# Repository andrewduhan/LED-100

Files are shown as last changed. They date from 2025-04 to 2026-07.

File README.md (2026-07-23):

**A drop-in replacement for early Stern & Bally lamp driver boards to make your lamps s~m~o~o~t~h again**

> ⚠️ **This is Rev 5 - work in progress.** 
> This board is still being developed and tested. Everything may change before release! 

---

## What is this?

Early Stern and Bally solid-state pinball machines (mid-1970s to the mid-80s) use incandescent bulbs. It's awesome to swap those bulbs for LEDs (less power draw, less heat, less maintenance)...  but: LEDs switch on and off instantly, and this makes old tables flash & strobe in a nasty way.

The LED-100 fixes that. You install it in place of the original board. It reads the lamp codes exactly like the original did, and drives your LEDs with a gentle fade - keep that warm glowing feel without the actual heat - your LEDs will behave more like real bulbs.

**Will this work for your machine?** See [Compatibility](#compatability) below.

---

## Will it work on my machine?

Two things have to be true:
1. Your machine was designed to use one of the supported lamp driver boards.
2. Every lamp this board controls has already been swapped with an LED. I don't know what it'll do if you try and drive incandescents.

**What this board does _not_ do:** it only drives the lamps that ran through the original lamp driver board. It has nothing to do with your machine's GI or any high-current feature/flasher lamps that are driven from the solenoid driver board. Those are separate systems and are not controlled by this board.

---

## How to use it

Once installed, there's nothing to operate - power the machine on and tit does what it does.

There are a couple of controls on the board.

- **s~m~o~o~t~h knob** - Turn this to adjust the fade-speed. All the way up will probably be way too gooey, all the way off will essentially diable the board, and your LEDs will snap on and off like before. (Fade-out is always a little slower than fade-in, 'cause that's now incandescent lamps work.)
- **A button and another knob** - These are placeholders right now. The button currently cycles through some demo/test modes, which ignore input from the MPU. The knob tweaks overall brightness.

---

## Installing it

The board is fully pin-compatible with the original — same connectors, same `J1`–`J4` labels, so swapping it in is straightforward:

1. **Turn off and unplug the machine.** C'mon.
2. Unplug the cables from the original lamp driver board. You might want to label the cables according to the markings on the board - `J1`, `J2`, `J3`, and `J4`
3. Unbolt and remove the original board from the backbox†.
4. Bolt the LED-100 into the backbox*.
5. Plug the same four cables onto the matching headers on the LED-100, `J1`-`J4`.  These are keyed, so check that they are oriented correctly.

†**Mounting (Rev 5)**: This board revision is much smaller than the original, so the mounting holes don't line up with the factory bolt points. You can get one bolt in, but not the rest. 
The final version will have a better mounting solution, but for now: secure it with the single bolt that does line up, and make sure no pins, traces, or solder joints on the back of the board are touching metal.

---

## What's in this git repository

Everything you need to understand, build, modify, or reproduce the board:

- **[`LED-100-hardware/`]()** — the circuit board: KiCad schematic and layout, plus the gerbers used to produce this rev.
- **[`LED-100-firmware/`]()** — the code that runs on the board's Teensy 4.0, with its own [README]() covering how it works, the pin map, and how to build and flash it.

---

## How It Works, the short technical version

The board reads the machine's original lamp-matrix signals, works out which lamps should be lit, and drives LEDs through three PWM LED drivers (TLC5947). A [Teensy 4.0] is the brain that runs the whole thing. The fade curves are calculated is done in software, so the glow-up and fade-out curves are adjustable. Full detail is in the [firmware README]().

Here's how the PCB looks in KiCad:

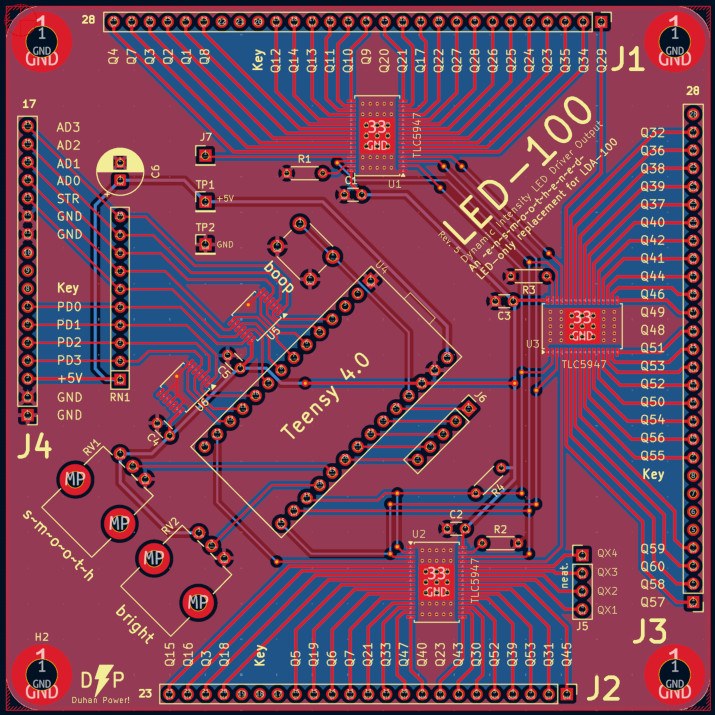
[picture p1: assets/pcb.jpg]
 

...and here's the schematic:

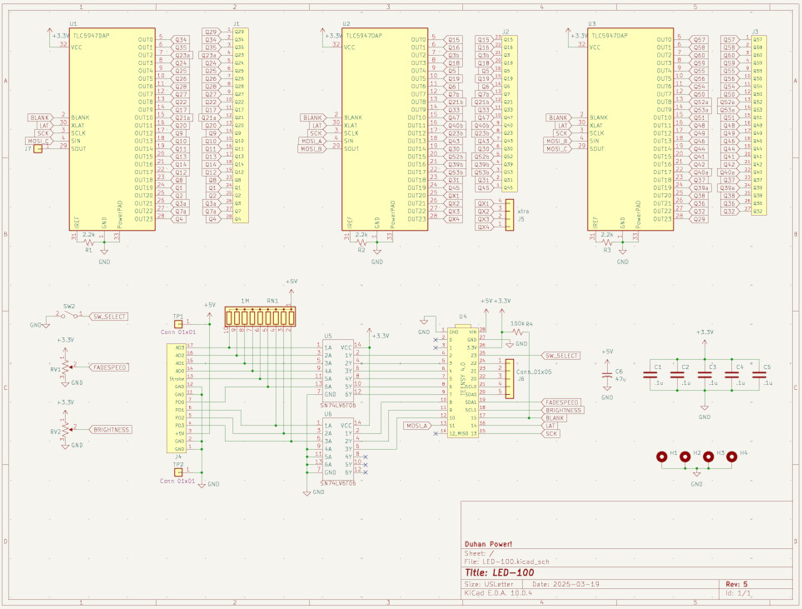
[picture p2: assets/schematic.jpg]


---

## Compatibility

> **NOTE:** The LED-100 doesn't yet work in any machine; this list is the _intended_ target, not a tested one. The **Stern LDA-100** is the active development board. Once it's working there, I'll try it in any compatible machine I can :)

The LED-100 is meant to replace several factory lamp driver boards, which are all electrically equivalent. 

| Board | Manufacturer |
| --- | --- |
| Stern LDA-100 | Stern |
| Stern LDB-100 | Stern |
| Bally AS-2518-14 | Bally |
| Bally AS-2518-23 | Bally |
| Bally A084-91612-A000 | Bally |

Not sure which board your machine has? Check the part number silkscreened on the original board, or your machine's service manual.

---

## License

Firmware and hardware are licensed under the terms in the LICENSE file, in their respective directories.

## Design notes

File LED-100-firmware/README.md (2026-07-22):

# LED-100 firmware

A drop-in replacement for the lamp-driver board in an early solid-state pinball
machine.

The machine's MPU still speaks its original lamp-matrix protocol. This board
listens to that protocol and drives LEDs — which have replaced the machine's
incandescent lamps — through three chained TLC5947 constant-current drivers. The
whole point is the **fade**: real incandescent bulbs glow up and die away, and
LEDs switched hard on and off look wrong in a way you notice immediately. This
board puts the glow back.

It runs on a **Teensy 4.0** under the Arduino IDE with Teensyduino.

---

## How it works, in one picture

```
   MPU lamp matrix ──▶ decoder ──┐
                                 ├──▶ one 64-bit lamp bitmap ──▶ fade engine ──▶ TLC5947 ──▶ LEDs
   bench demo modes ─────────────┘
```

The MPU and the built-in demo modes are interchangeable sources: both hand off a
completed "which lamps are lit" bitmap the exact same way, so everything after
that point behaves identically whether you're driving from a real machine or
from a bench pattern.

---

## Hardware

- **Teensy 4.0** — the microcontroller.
- **Interface board** — sits between the MPU and the Teensy. The MPU's signals
  are 5 V and the Teensy's pins are 3.3 V-only, so the interface board handles
  the level shifting. **Heads up:** the current prototype interface board may
  have damaged some Teensy input pins by feeding them 5 V directly; a redesign is
  on the way. Until it lands, treat the live-decode path as unverified (the fade
  side is fully working — see [Status](#status)).
- **Three TLC5947 drivers**, chained — 24 channels each, 72 total, of which 60
  correspond to the original machine's lamps.
- **LEDs** in place of the original incandescent lamps.
- A **momentary push-button** (mode select) and a **potentiometer** (fade speed)
  on the front panel. A second pot is on the board but isn't read by the firmware
  yet.

### Pin map

The authoritative copy of this lives in the `#define`s at the top of
[`LED-100-firmware.ino`](LED-100-firmware.ino) — if these ever disagree,
believe the code.

| Signal | Teensy pin | Notes |
| --- | --- | --- |
| AD0–AD3 | 5, 4, 3, 2 | Address lines from the MPU |
| PD0–PD3 | 7, 8, 9, 10 | Group-enable lines (the original board's W/X/Y/Z) |
| STROBE | 6 | Address latch |
| TLC clock / data / latch / blank | 13 / 12 / 14 / 15 | To the first TLC5947 |
| Mode button | 23 | Momentary to ground |
| Fade-speed pot | A3 | Wiper to the pin, ends to 3.3 V and ground |
| Second pot | A2 | Placeholder — on the board, nothing reads it yet |

Signal names follow the original board's schematic, so the code, a scope probe,
and the machine's service manual all use the same labels.

### Wiring the TLC5947 BLANK pin

This is the one wiring detail most likely to trip you up, so it's called out
here as well as in the driver header. Best option first:

1. **BLANK → a Teensy pin, with a pull-up resistor to 3.3 V** (what this board
   does). Clean startup, no dimming. Recommended.
2. **BLANK tied to ground**, not wired to the Teensy. Works, but you'll get a
   brief flash of garbage at power-on and slightly dimmer LEDs *while they're
   fading*. Neither is fixable in software.

The full explanation is in the header comment of
[`TLC5947.h`](TLC5947.h).

---

## Using it

**Normal operation** needs no interaction: power it up and it decodes the MPU
and drives the lamps.

**The push-button** cycles between live input and three LED test patterns —
random, flash-all, and sequential. The patterns ignore the MPU entirely, which
makes them handy for checking the LEDs and the fade feel on the bench with
nothing else connected. They're a development aid and may not survive to the
final build (`ENABLE_DEMO_MODES` in the sketch drops them, and the button with
them); what the button ends up doing on a finished board is still open.

**The potentiometer** sets the fade speed. Fade-out is always slower than
fade-in, mimicking how a filament cools more slowly than it heats. It's meant to
be set once with the backbox open and then left alone.

---

## Configuring it

The knobs a builder actually touches, all near the top of
[`LED-100-firmware.ino`](LED-100-firmware.ino):

- **`FADE_IN_CURVE` / `FADE_OUT_CURVE`** — the shape of the glow-up and
  die-away. Pick from the curves the fade engine offers
  ([`FadeEngine.h`](FadeEngine.h)).
- **`FADE_IN_MIN_MS` / `FADE_IN_MAX_MS` / `FADE_OUT_RATIO`** — the range the pot
  sweeps, and how much slower fade-out is than fade-in.
- **`NUM_TLC5947`** — number of chained driver chips, if your board differs.
- **Software vs. hardware SPI** — the driver supports both. This board currently
  uses bit-banged software SPI (the constructor call just below the pin
  `#define`s); the driver header explains the switch.

The **lamp map** — which of the 72 driver channels each incoming lamp lights — is
the `channelToLampBit` table in the sketch. It's specific to the machine and its
wiring, and is the thing to edit if a lamp lights the wrong LED.

---

## Building & flashing

1. Install the **Arduino IDE** and **[Teensyduino](https://www.pjrc.com/teensy/td_download.html)**.
2. Open [`LED-100-firmware.ino`](LED-100-firmware.ino).
3. Select **Tools → Board → Teensy 4.0**.
4. Upload.

No libraries to install: the `TLC5947` driver and the `FadeEngine` both live in
the sketch folder alongside the `.ino`.

---

## Status

- **Fade engine — working.** Demonstrated by the demo modes; this is the mature
  part of the project.
- **Live MPU decode — unverified.** The logic is written and reviewed, but can't
  be trusted on hardware until the redesigned interface board arrives (see
  [Hardware](#hardware)).
- **Lamp map — not yet reconciled.** `channelToLampBit` hasn't been checked
  against the real machine and is known to be at least partly wrong: a few driver
  channels are currently mapped to lamp positions that can never light, and a few
  real lamps aren't mapped to any channel. Flagged in the code; a proper pass is
  pending.

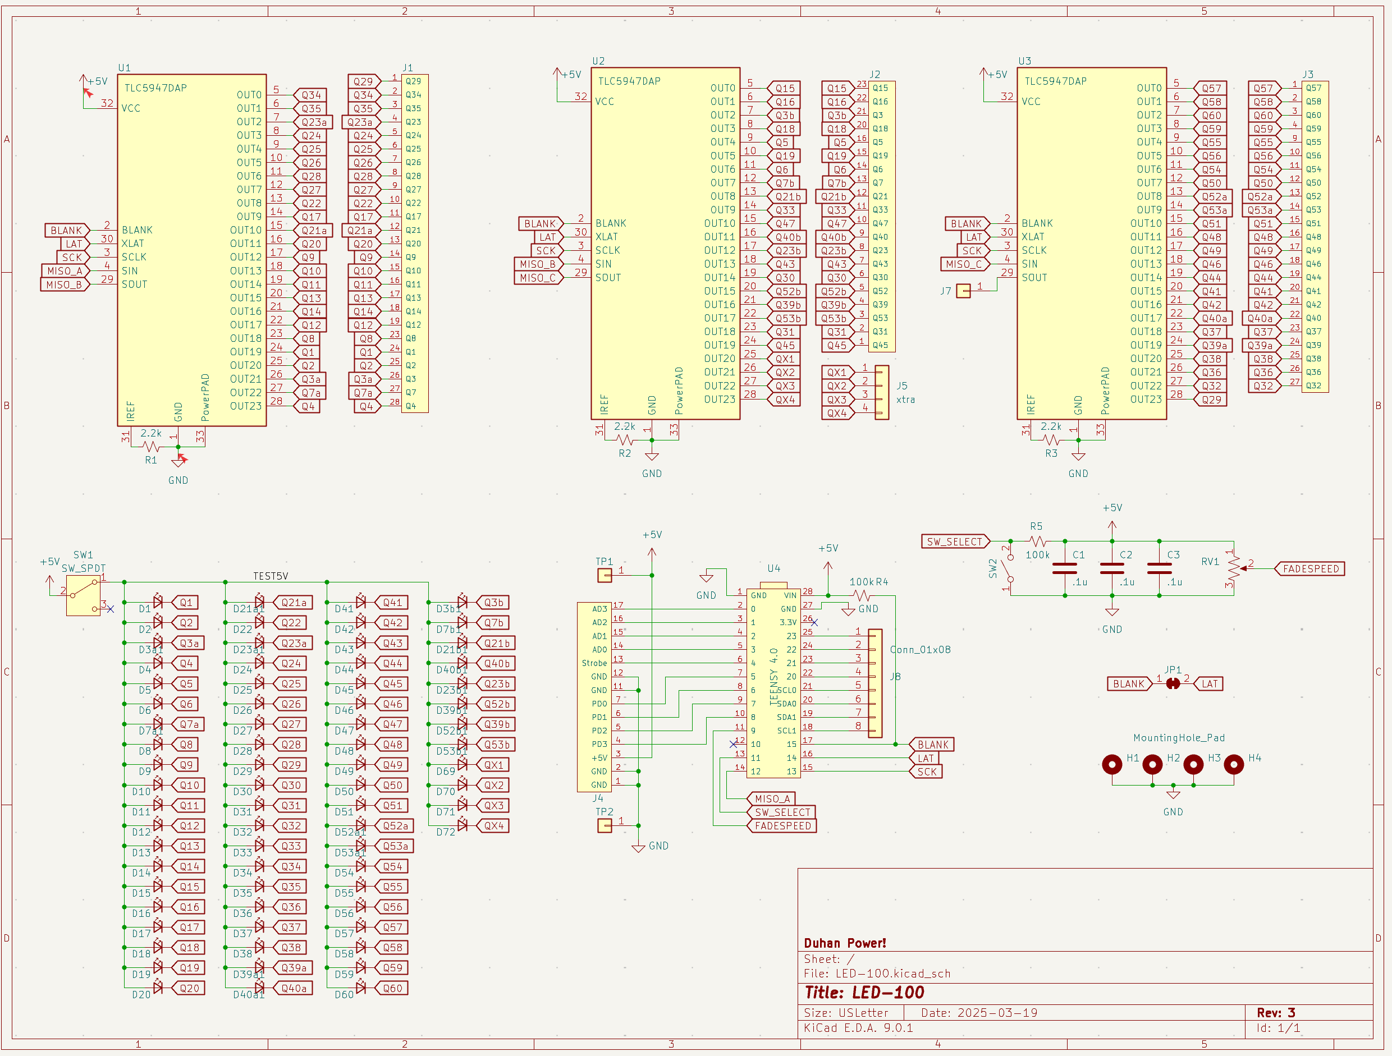
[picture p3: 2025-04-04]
assets/schematic.png

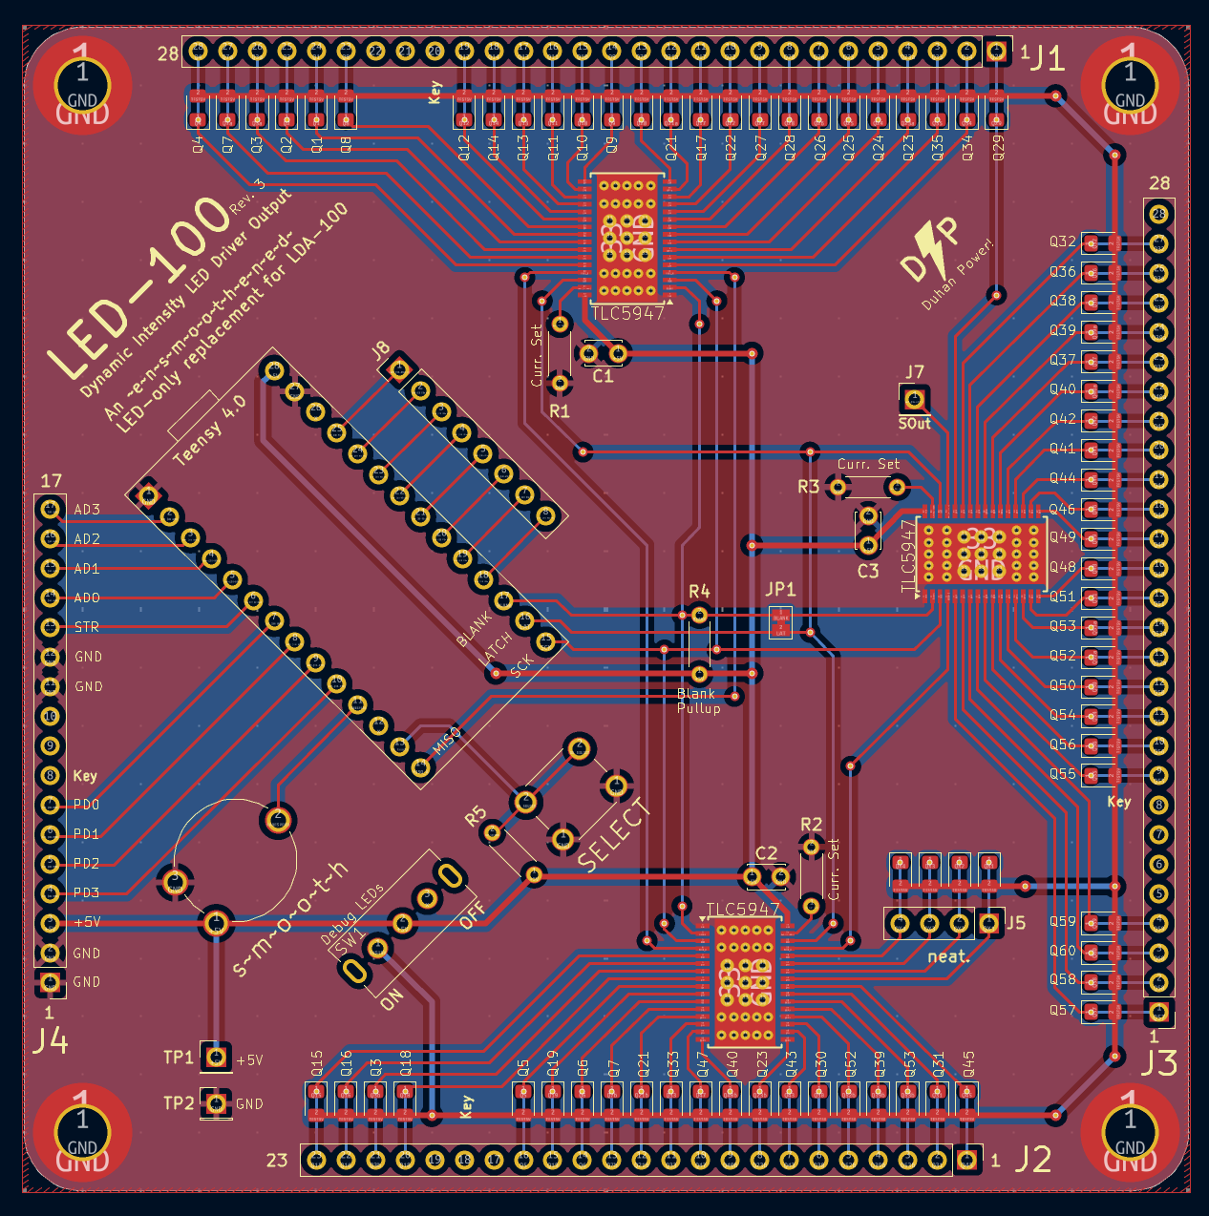
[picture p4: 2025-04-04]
assets/pcb.png

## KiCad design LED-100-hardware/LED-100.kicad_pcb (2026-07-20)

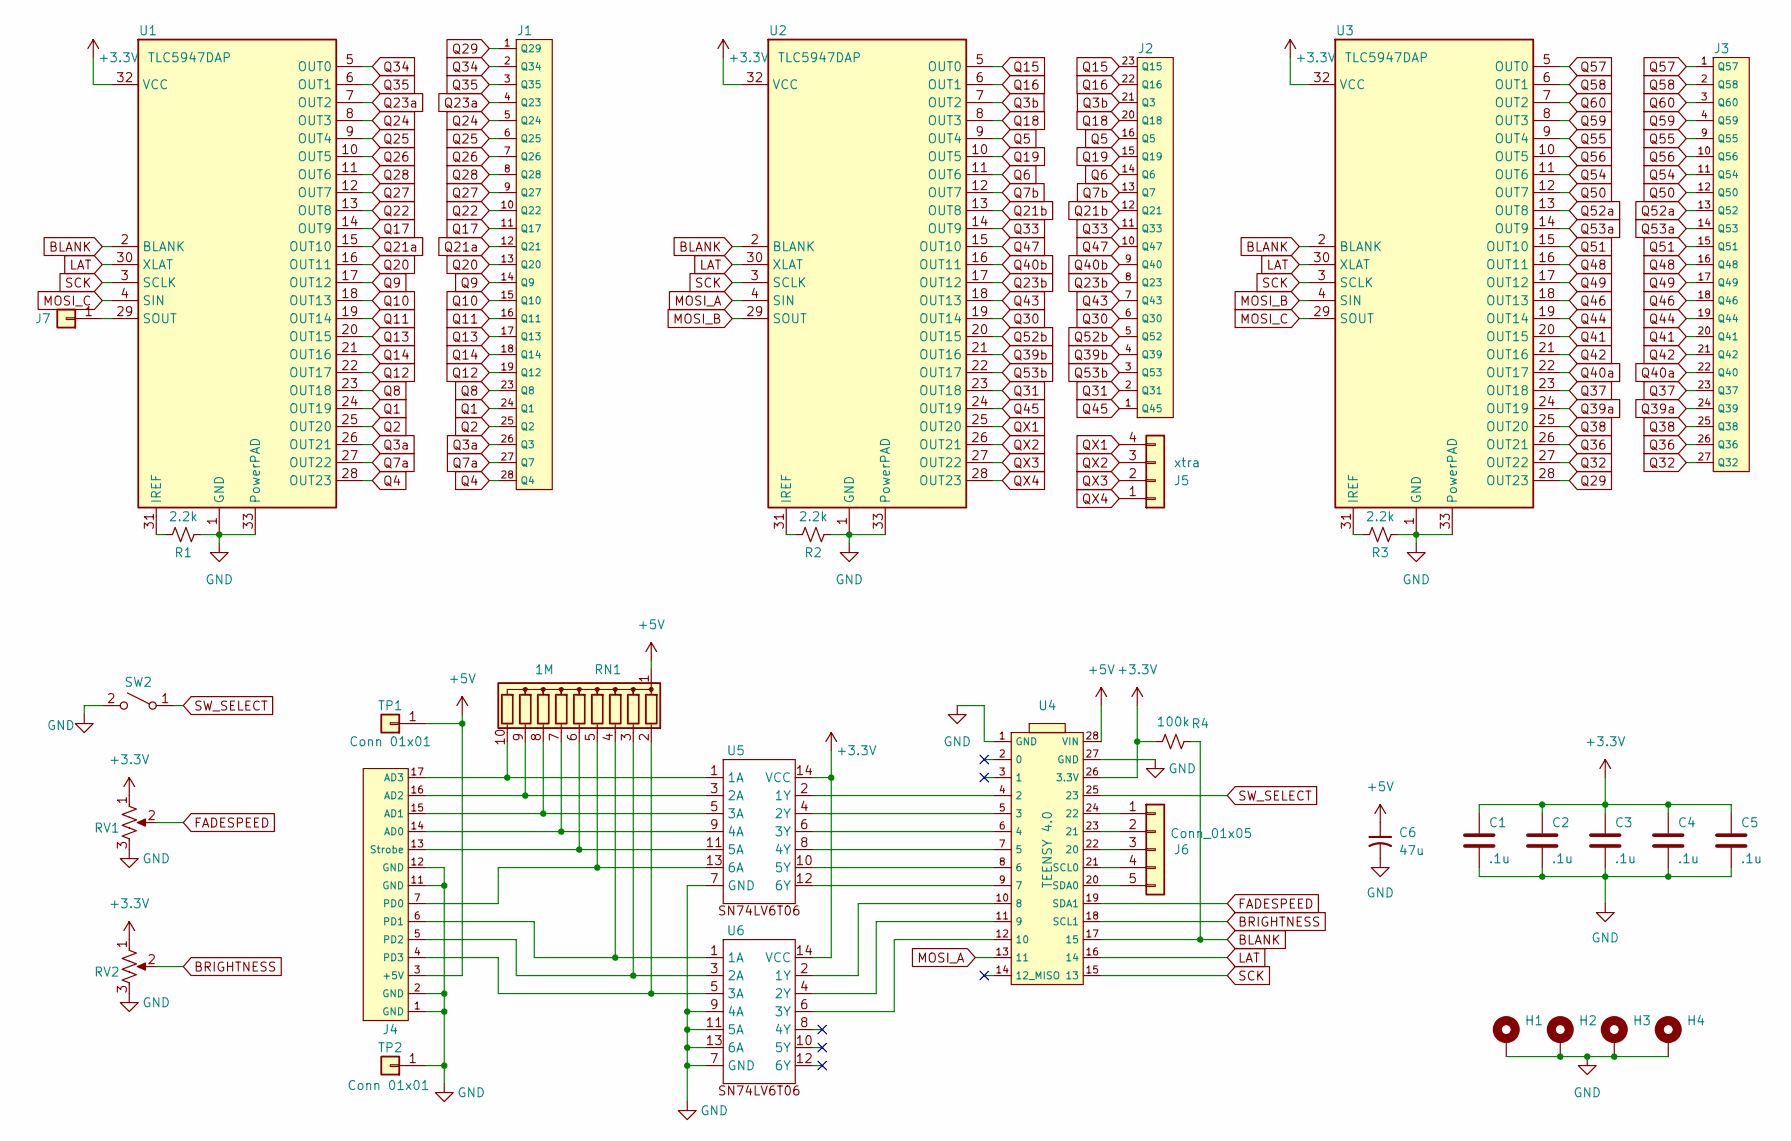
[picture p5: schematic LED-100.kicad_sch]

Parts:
C1, C2, C3, C4, C5: .1u; C_Disc_D3.0mm_W1.6mm_P2.50mm
C6: 47u; CP_Radial_D6.3mm_P2.50mm
H1, H2, H3, H4: MountingHole_Pad; MountingHole_4.3mm_M4_Pad_TopBottom
J1: PinHeader_1x28_P2.54mm_Vertical
J2: LDA100_2_J2; PinHeader_1x23_P2.54mm_Vertical
J3: LDA100_2_J3; PinHeader_1x28_P2.54mm_Vertical
J4: LDA100_2_J4; PinHeader_1x17_P2.54mm_Vertical
J5: xtra; PinHeader_1x04_P2.54mm_Vertical
J6: Conn_01x05; PinHeader_1x05_P2.54mm_Vertical
J7: Conn_01x01; PinHeader_1x01_P2.54mm_Vertical
R1, R2, R3: 2.2k; R_Axial_DIN0204_L3.6mm_D1.6mm_P5.08mm_Horizontal
R4: 100k; R_Axial_DIN0204_L3.6mm_D1.6mm_P5.08mm_Horizontal
RN1: 1M; R_Array_SIP10
RV1, RV2: 100k; Potentiometer_Bourns_PTV09A-1_Single_Vertical
SW2: SW_SPST; SW_PUSH_6mm_H5mm
TP1, TP2: Conn_01x01; PinHeader_1x01_P2.54mm_Vertical
U1, U2, U3: TLC5947DAP; Package_SO_HTSSOP-32-1EP_6.1x11mm_P0.65mm_EP5.2x11mm_Mask4.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
U4: TEENSY 4.0; Teensy 4.0
U5, U6: TSSOP-14_4.4x5mm_P0.65mm

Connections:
+3.3V: C1.1, C2.1, C3.1, C4.1, C5.1, R4.1, RV1.1, RV2.1, U1.32 (VCC), U2.32 (VCC), U3.32 (VCC), U4.26 (3.3V), U5.14 (VCC), U6.14 (VCC)
+5V: C6.1, J4.3 (+5V), RN1.1 (common), TP1.1 (Pin_1_1), U4.28 (VIN)
BLANK: R4.2, U1.2 (BLANK), U2.2 (BLANK), U3.2 (BLANK), U4.17 (15)
BRIGHTNESS: RV2.2, U4.18 (SCL1)
FADESPEED: RV1.2, U4.19 (SDA1)
GND: C1.2, C2.2, C3.2, C4.2, C5.2, C6.2, H1.1 (1_1), H2.1 (1_1), H3.1 (1_1), H4.1 (1_1), J4.1 (GND), J4.2 (GND), J4.11 (GND), J4.12 (GND), R1.2, R2.2, R3.2, RV1.3, RV2.3, SW2.2 (B), TP2.1 (Pin_1_1), U1.1 (GND), U1.33 (PowerPAD), U2.1 (GND), U2.33 (PowerPAD), U3.1 (GND), U3.33 (PowerPAD), U4.1 (GND), U4.27 (GND), U5.7 (GND), U6.7 (GND), U6.9 (4A), U6.11 (5A), U6.13 (6A)
LAT: U1.30 (XLAT), U2.30 (XLAT), U3.30 (XLAT), U4.16 (14)
MOSI_A: U2.4 (SIN), U4.13 (11)
MOSI_B: U2.29 (SOUT), U3.4 (SIN)
MOSI_C: U1.4 (SIN), U3.29 (SOUT)
unnamed: J4.14 (AD0), RN1.7 (R6), U5.9 (4A)
unnamed: J4.15 (AD1), RN1.8 (R7), U5.5 (3A)
unnamed: J4.16 (AD2), RN1.9 (R8), U5.3 (2A)
unnamed: J4.17 (AD3), RN1.10 (R9), U5.1 (1A)
unnamed: J4.7 (PD0), RN1.5 (R4), U5.13 (6A)
unnamed: J4.6 (PD1), RN1.4 (R3), U6.1 (1A)
unnamed: J4.5 (PD2), RN1.3 (R2), U6.3 (2A)
unnamed: J4.4 (PD3), RN1.2 (R1), U6.5 (3A)
unnamed: J4.13 (Strobe), RN1.6 (R5), U5.11 (5A)
unnamed: J6.1, U4.24 (22)
unnamed: J6.2, U4.23 (21)
unnamed: J6.3, U4.22 (20)
unnamed: J6.4, U4.21 (SCL0)
unnamed: J6.5, U4.20 (SDA0)
unnamed: J7.1 (Pin_1_1), U1.29 (SOUT)
unnamed: R1.1, U1.31 (IREF)
unnamed: R2.1, U2.31 (IREF)
unnamed: R3.1, U3.31 (IREF)
unnamed: U4.4 (2), U5.2 (1Y)
unnamed: U4.5 (3), U5.4 (2Y)
unnamed: U4.6 (4), U5.6 (3Y)
unnamed: U4.7 (5), U5.8 (4Y)
unnamed: U4.8 (6), U5.10 (5Y)
unnamed: U4.9 (7), U5.12 (6Y)
unnamed: U4.10 (8), U6.2 (1Y)
unnamed: U4.11 (9), U6.4 (2Y)
unnamed: U4.12 (10), U6.6 (3Y)
Q1: J1.24 (Q1), U1.24 (OUT19)
Q2: J1.25 (Q2), U1.25 (OUT20)
Q3a: J1.26 (Q3), U1.26 (OUT21)
Q3b: J2.21 (Q3), U2.7 (OUT2)
Q4: J1.28 (Q4), U1.28 (OUT23)
Q5: J2.16 (Q5), U2.9 (OUT4)
Q6: J2.14 (Q6), U2.11 (OUT6)
Q7a: J1.27 (Q7), U1.27 (OUT22)
Q7b: J2.13 (Q7), U2.12 (OUT7)
Q8: J1.23 (Q8), U1.23 (OUT18)
Q9: J1.14 (Q9), U1.17 (OUT12)
Q10: J1.15 (Q10), U1.18 (OUT13)
Q11: J1.16 (Q11), U1.19 (OUT14)
Q12: J1.19 (Q12), U1.22 (OUT17)
Q13: J1.17 (Q13), U1.20 (OUT15)
Q14: J1.18 (Q14), U1.21 (OUT16)
Q15: J2.23 (Q15), U2.5 (OUT0)
Q16: J2.22 (Q16), U2.6 (OUT1)
Q17: J1.11 (Q17), U1.14 (OUT9)
Q18: J2.20 (Q18), U2.8 (OUT3)
Q19: J2.15 (Q19), U2.10 (OUT5)
Q20: J1.13 (Q20), U1.16 (OUT11)
Q21a: J1.12 (Q21), U1.15 (OUT10)
Q21b: J2.12 (Q21), U2.13 (OUT8)
Q22: J1.10 (Q22), U1.13 (OUT8)
Q23a: J1.4 (Q23), U1.7 (OUT2)
Q23b: J2.8 (Q23), U2.17 (OUT12)
Q24: J1.5 (Q24), U1.8 (OUT3)
Q25: J1.6 (Q25), U1.9 (OUT4)
Q26: J1.7 (Q26), U1.10 (OUT5)
Q27: J1.9 (Q27), U1.12 (OUT7)
Q28: J1.8 (Q28), U1.11 (OUT6)
Q29: J1.1 (Q29), U3.28 (OUT23)
Q30: J2.6 (Q30), U2.19 (OUT14)
Q31: J2.2 (Q31), U2.23 (OUT18)
Q32: J3.27 (Q32), U3.27 (OUT22)
Q33: J2.11 (Q33), U2.14 (OUT9)
Q34: J1.2 (Q34), U1.5 (OUT0)
Q35: J1.3 (Q35), U1.6 (OUT1)
Q36: J3.26 (Q36), U3.26 (OUT21)
Q37: J3.23 (Q37), U3.23 (OUT18)
Q38: J3.25 (Q38), U3.25 (OUT20)
Q39a: J3.24 (Q39), U3.24 (OUT19)
Q39b: J2.4 (Q39), U2.21 (OUT16)
Q40a: J3.22 (Q40), U3.22 (OUT17)
Q40b: J2.9 (Q40), U2.16 (OUT11)
Q41: J3.20 (Q41), U3.20 (OUT15)
Q42: J3.21 (Q42), U3.21 (OUT16)
Q43: J2.7 (Q43), U2.18 (OUT13)
Q44: J3.19 (Q44), U3.19 (OUT14)
Q45: J2.1 (Q45), U2.24 (OUT19)
Q46: J3.18 (Q46), U3.18 (OUT13)
Q47: J2.10 (Q47), U2.15 (OUT10)
Q48: J3.16 (Q48), U3.16 (OUT11)
Q49: J3.17 (Q49), U3.17 (OUT12)
Q50: J3.12 (Q50), U3.12 (OUT7)
Q51: J3.15 (Q51), U3.15 (OUT10)
Q52a: J3.13 (Q52), U3.13 (OUT8)
Q52b: J2.5 (Q52), U2.20 (OUT15)
Q53a: J3.14 (Q53), U3.14 (OUT9)
Q53b: J2.3 (Q53), U2.22 (OUT17)
Q54: J3.11 (Q54), U3.11 (OUT6)
Q55: J3.9 (Q55), U3.9 (OUT4)
Q56: J3.10 (Q56), U3.10 (OUT5)
Q57: J3.1 (Q57), U3.5 (OUT0)
Q58: J3.2 (Q58), U3.6 (OUT1)
Q59: J3.4 (Q59), U3.8 (OUT3)
Q60: J3.3 (Q60), U3.7 (OUT2)
QX1: J5.4, U2.25 (OUT20)
QX2: J5.3, U2.26 (OUT21)
QX3: J5.2, U2.27 (OUT22)
QX4: J5.1, U2.28 (OUT23)
SCK: U1.3 (SCLK), U2.3 (SCLK), U3.3 (SCLK), U4.15 (13)
SW_SELECT: SW2.1 (A), U4.25 (23)

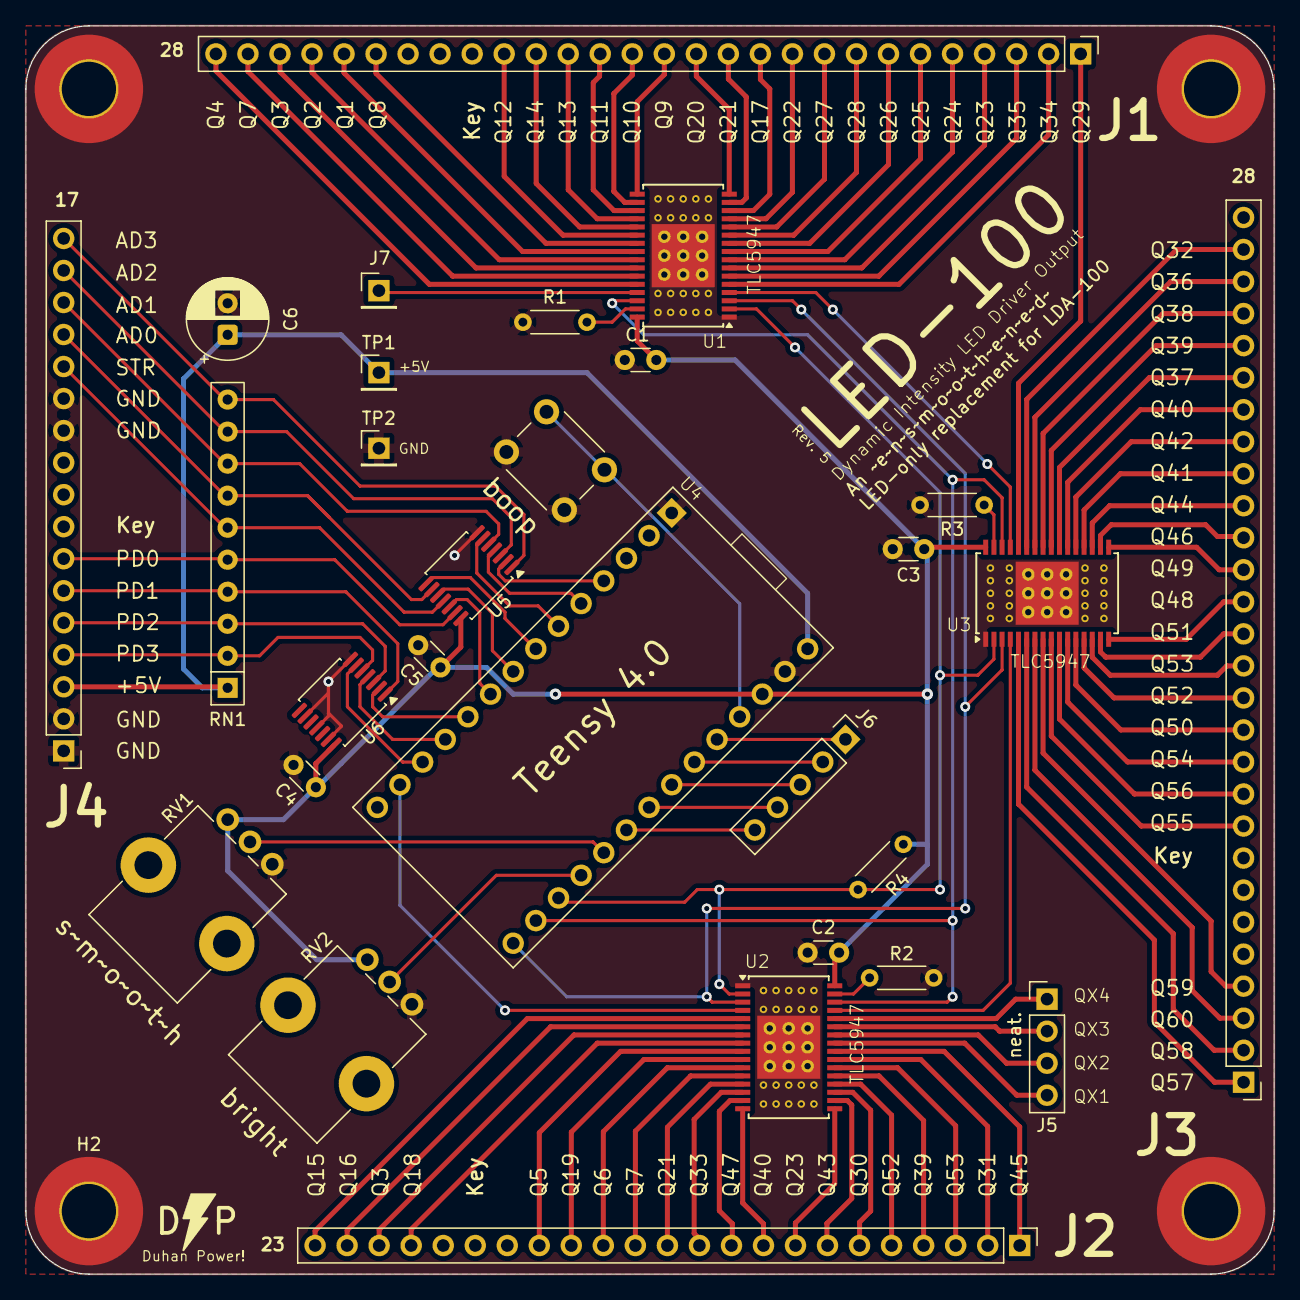
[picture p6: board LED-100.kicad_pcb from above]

Board: 2 copper layers, 99.0 x 99.0 mm, 33 parts (0 on the bottom side), 111 nets.

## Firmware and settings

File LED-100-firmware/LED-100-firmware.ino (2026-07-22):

/*
  Lamp-matrix decoder -> fade engine -> TLC5947 driver
  Teensy 4.0 / TeensyDuino

  Replaces the lamp-driver board in an early solid-state pinball machine.
  The MPU still speaks its original lamp-matrix protocol; this board decodes it, and drives LEDs (which have replaced the machine's
  incandescent lamps) through three chained TLC5947 constant-current drivers. The point of the exercise is the fade: incandescent 
  lamps glow up and die away, and LEDs switched hard on and off look wrong in a way you notice immediately.

  Signal names match the original board's schematic, so that this code, a scope probe and the service manual all agree:
    AD0..AD3  - the 4 address lines
    PD0..PD3  - the 4 group-enable lines (the original W/X/Y/Z)
    STROBE    - address latch

  PROTOCOL
  --------
  - All 9 input lines idle HIGH -> INPUT_PULLUP throughout.
  - AD0..AD3 carry an address 0-15, latched on STROBE's rising edge (STROBE is active-HIGH).
  - PD0..PD3 are active-LOW, driven by 4 parallel latching decoders (MC14514B) fed from the same address lines. Critically, they 
    assert *after* STROBE - each pulses low independently, sometime before the next STROBE. They are NOT sampled at the same 
    instant as the address. A falling edge on one of them means "the address STROBE most recently latched applies to my group", 
    so capture reacts to PD edges directly rather than reading all four at strobe time.
  - Addresses 0-14 are the 15 data addresses. 15 addresses x 4 groups = the 60 lamps of the original matrix. A lamp is identified 
    throughout this file by its bit index:  lampBit = pd * 16 + addr.
  - Address 15 is the end-of-frame sentinel and carries no data.
  - Frames arrive tied to AC zero-crossing (~120/sec), not a fixed clock. A whole 16-strobe frame completes well inside one 
    ~8.3ms half-cycle, so there is no time pressure on any ISR here.

  SHARING THE BUS WITH ANOTHER BOARD
  ----------------------------------
  Another board strobes this same bus, and its traffic has to be rejected. Two facts, both confirmed on the bench, make that possible:

  1. Interloper strobes only ever report address 15 (their decoder's "15" output is deliberately left unconnected). They never 
    present 0-14. So any address in 0-14 is ours and can be accepted on sight.

  2. Address 15 is therefore ambiguous - it is both our end-of-frame marker and every interloper strobe. Context resolves it: 
    a genuine end-of-frame 15 only ever arrives directly after address 14, the last data address. A 15 seen at any other moment 
    is an interloper, and is ignored.

  Interloper strobes also make their own PD lines pulse, which would otherwise look like real data for whatever address we last 
  latched. So a PD pulse is only trusted if no strobe of any kind has moved the bus since we latched: lastStrobeAddr must still 
  equal latchedAddr. If the interloper strobed in between, lastStrobeAddr changed while latchedAddr did not, and the mismatch 
  discards the pulse.

  Address 0 reliably marks a genuine frame start (confirmed it doesn't appear as noise), so it doubles as the resync point.

  ARCHITECTURE
  ------------
  Everything flows through one 64-bit lamp bitmap, published once per frame:

      decoder ISRs  --\
                       >-- publishFrame() -> takeFrame() -> FadeEngine -> TLC5947
      demo modes    --/

  The demo modes are a stand-in for the MPU: they publish frames exactly as the decoder does, so every stage downstream is 
  identical whether the lamps are being driven by a real machine or by a bench pattern. Deleting the demos for the final build 
  means deleting one section and one call.

  The five pin ISRs are the only interrupt code in the project. Fading runs on a timer gate in loop(), which is otherwise idle - 
  the fade needs to be regular, not instantaneous, and keeping it out of interrupt context is what lets it be an ordinary object 
  with no volatile state.
*/

#include "TLC5947.h"
#include "FadeEngine.h"

// Set to 0 for the final build: drops the bench demo patterns and the button that cycles them, leaving only live decode.
#define ENABLE_DEMO_MODES 1

// Set to 0 for the final build: drops the CPU load meter and its Serial output. See the LOAD METER section below.
#define ENABLE_LOAD_METER 1

// ==================================================================
// Configuration
// ==================================================================

// ---- TLC5947 LED drivers ----
#define NUM_TLC5947   3
#define NUM_CHANNELS  (NUM_TLC5947 * 24)   // 72
#define MAX_LEVEL     4095                 // TLC5947 is 12-bit

// Software (bit-banged) SPI. The prototype interface board has the data pin mis-assigned, so hardware SPI is not usable on it; 
// the driver supports both, and this becomes the hardware-SPI constructor once the redesigned board arrives. Bit-banging 72 
// channels costs ~150us per write, which at the fade tick rate below is a few percent of one core. It is not a problem.
#define TLC_CLOCK 13
#define TLC_DATA  12
#define TLC_LATCH 14
#define TLC_BLANK 15
TLC5947 tlc(NUM_TLC5947, TLC_CLOCK, TLC_DATA, TLC_LATCH, TLC_BLANK);

// ---- Inputs from the MPU ----
#define PIN_AD0    5
#define PIN_AD1    4
#define PIN_AD2    3
#define PIN_AD3    2
#define PIN_PD0    7
#define PIN_PD1    8
#define PIN_PD2    9
#define PIN_PD3    10
#define PIN_STROBE 6   // must be interrupt-capable (all Teensy 4 pins are)

// ---- Front-panel controls ----
#define PIN_DEMO_SWITCH 23   // momentary to GND -> pullup, active low
#define PIN_POT_FADE    A3   // one pot; sets fade-in, fade-out follows it
#define PIN_POT_BRIGHT  A2   // placeholder: the pot is on the board but nothing reads it yet. Current idea is scaling max output
                             // brightness below 100%, but it may become fade-out time instead, or be dropped to save BOM cost.

// ---- Fade behaviour ----
const uint32_t FADE_TICK_MS = 5;     // 200Hz; well above flicker perception

// The pot sets the fade-in time; fade-out is always this much slower, to mimic a filament cooling more slowly than it heats.
const uint16_t FADE_IN_MIN_MS  = 10;
const uint16_t FADE_IN_MAX_MS  = 200;
const float    FADE_OUT_RATIO  = 3.5f;   // so fade-out spans 35ms .. 700ms

const FadeCurve FADE_IN_CURVE  = FadeCurve::ExpoIn;
const FadeCurve FADE_OUT_CURVE = FadeCurve::LogOut;

FadeEngine fade(NUM_CHANNELS, MAX_LEVEL);

// ---- Control polling ----
const uint32_t POT_POLL_MS    = 250;   // set once with the backbox open, then never touched - slow is fine, and the deadband 
const uint16_t POT_DEADBAND   = 8;     // stops ADC noise wobbling the fade times between polls matches analogReadResolution(10)
const uint16_t POT_MAX        = 1023;  // matches analogReadResolution(10)
const uint32_t DEBOUNCE_MS    = 50;

// ==================================================================
// Lamp map
// ==================================================================
// Which lamp bit (pd * 16 + addr) drives which TLC5947 output channel. Several channels legitimately share a bit: some original 
// lamp drivers fed two SCRs, lighting the same signal on both the playfield and the backbox.
// DED marks a channel nothing drives; it is a dark-emitting LED.
//
// NOTE: this table has not yet been reconciled against the original board and is known to be at least partly wrong. 
// Channels 58, 68 and 71 map to bits 47, 31 and 15 - all of which are addr==15, the end-of-frame sentinel, so no PD pulse can 
// ever set them and those channels can never light. Lamp bits 60, 61 and 62 are meanwhile mapped to no channel at all. Left 
// as-is deliberately, pending a proper review against the machine.
const uint8_t DED = 0xFF;

const uint8_t channelToLampBit[NUM_CHANNELS] = {
  27, 12, 10, 28, 13, 29, 14, 11, 26, 42, 57, 40, 25, 58, 43, 55, 41, 56, 44, 59, DED, DED, DED, DED,
  45, 52, 50, 51, 49, 53, 48, 46, 55, 56, 47, 34, 33, 54, 32, 39, 38, 40, 35, 41, 31, 30, 36, 15,
  19, 18, 25, 23, 22, 21, 17, 16, 20, 24, 26, 37,  4,  5,  6,  2,  0,  1,  3,  8,  9, 10, 11,  7
};
static_assert(sizeof(channelToLampBit) == NUM_CHANNELS, "lamp map must have exactly one entry per TLC5947 channel");

// ==================================================================
// Frame handoff
// ==================================================================
// The one place a completed lamp bitmap is published, and the one place it is consumed. The decoder publishes from an ISR; 
// the demo modes publish from loop(). A uint64_t is not written atomically on a 32-bit core, so both ends guard the access - 
// and they do so by saving and restoring the interrupt mask rather than blindly re-enabling, which keeps them correct whether 
// the caller is inside an ISR or not.

// Which producer owns the handoff. Live is the real machine; the rest are bench patterns (see ENABLE_DEMO_MODES). 
// Exactly one publishes at a time.
enum class LampSource : uint8_t { Live, RandomFlicker, Blink, Chase };
volatile LampSource lampSource = LampSource::Live;

volatile uint64_t pendingFrame = 0;
volatile bool     frameFresh   = false;

// Save-and-restore of the interrupt mask, rather than noInterrupts() / interrupts(). The difference matters: 
// interrupts() unconditionally re-enables, so calling it from inside an ISR would drop the mask early.
// publishFrame() is called from an ISR (decode) and from loop() (demos), so it has to be correct in both.
static inline uint32_t irqSave() {
  uint32_t primask;
  __asm__ volatile("MRS %0, primask" : "=r"(primask) :: "memory");
  __asm__ volatile("CPSID i" ::: "memory");
  return primask;
}

static inline void irqRestore(uint32_t primask) {
  __asm__ volatile("MSR primask, %0" :: "r"(primask) : "memory");
}

void publishFrame(uint64_t lampBits) {
  const uint32_t mask = irqSave();
  pendingFrame = lampBits;
  frameFresh   = true;
  irqRestore(mask);
}

// Returns false if no new frame has arrived since the last call.
bool takeFrame(uint64_t &out) {
  bool got = false;
  const uint32_t mask = irqSave();
  if (frameFresh) {
    out        = pendingFrame;
    frameFresh = false;
    got        = true;
  }
  irqRestore(mask);
  return got;
}

// ==================================================================
// Decoder
// ==================================================================

const uint8_t ADDR_FRAME_START = 0;     // also the resync point
const uint8_t ADDR_LAST_DATA   = 14;    // 0..14 carry lamp data
const uint8_t ADDR_END_FRAME   = 15;    // sentinel; also every interloper strobe
const uint8_t ADDR_NONE        = 0xFF;  // no frame in progress

// Written by strobeISR, read by the PD ISRs.
volatile uint8_t latchedAddr    = ADDR_NONE;  // the address the current frame is on
volatile uint8_t lastStrobeAddr = ADDR_NONE;  // the address on the most recent strobe of ANY kind, ours or an interloper's

// The frame being accumulated, one uint16 per PD group, one bit per address.
// Private to the ISRs; packed into a uint64 and published at end-of-frame.
volatile uint16_t pdBits[4] = {0, 0, 0, 0};

// Tracks the current frame's address. Touches no PD line.
void strobeISR() {
  const uint8_t addr = digitalReadFast(PIN_AD0)
                     | (digitalReadFast(PIN_AD1) << 1)
                     | (digitalReadFast(PIN_AD2) << 2)
                     | (digitalReadFast(PIN_AD3) << 3);

  lastStrobeAddr = addr;   // recorded whether or not we accept it below

  if (addr == ADDR_FRAME_START) {
    pdBits[0] = pdBits[1] = pdBits[2] = pdBits[3] = 0;
    latchedAddr = ADDR_FRAME_START;
    return;
  }

  if (addr == ADDR_END_FRAME) {
    // Only a genuine end-of-frame if we just finished the last data address.
    // Anything else reporting 15 is the other board on the bus.
    if (latchedAddr == ADDR_LAST_DATA) {
      // Keep decoding while a demo runs, but don't publish - 
      // the demo owns the handoff, and a live MPU would otherwise fight it for the lamps.
      if (lampSource == LampSource::Live) {
        publishFrame((uint64_t)pdBits[0]
                   | ((uint64_t)pdBits[1] << 16)
                   | ((uint64_t)pdBits[2] << 32)
                   | ((uint64_t)pdBits[3] << 48));
      }
      latchedAddr = ADDR_NONE;
    }
    return;
  }

  // Addresses 1-14 only mean anything once a frame has actually started.
  if (latchedAddr != ADDR_NONE) latchedAddr = addr;
}

// A PD line has gone low: its decoder is presenting its latched output, so the lamp at (this group, the latched address) is lit.
// Trust it only if no strobe has moved the bus since we latched that address - otherwise this pulse belongs to another board's 
// traffic, not ours.
inline void pdFallingEdge(uint8_t pd) {
  if (latchedAddr != ADDR_NONE && latchedAddr == lastStrobeAddr) {
    pdBits[pd] |= (uint16_t)1 << latchedAddr;
  }
}

void pd0ISR() { pdFallingEdge(0); }
void pd1ISR() { pdFallingEdge(1); }
void pd2ISR() { pdFallingEdge(2); }
void pd3ISR() { pdFallingEdge(3); }

// ==================================================================
// Demo modes  (bench only - see ENABLE_DEMO_MODES)
// ==================================================================
// These publish frames exactly as the decoder does, so they exercise the real lamp map and the real fade path. While a demo runs, 
// strobeISR keeps decoding but stops publishing, so a live MPU on the bus is simply ignored.

#if ENABLE_DEMO_MODES

const uint8_t LAMP_COUNT = 60;   // 15 addresses x 4 PD groups

// The 60 real lamp bit indices, in order - the demos step through these rather than through raw channel numbers, 
// so they only ever light bits the protocol could actually deliver.
uint8_t lampBitIndex[LAMP_COUNT];
uint64_t allLampsMask = 0;

void buildLampBitIndex() {
  uint8_t n = 0;
  for (uint8_t pd = 0; pd < 4; pd++) {
    for (uint8_t addr = 0; addr <= ADDR_LAST_DATA; addr++) {
      const uint8_t bit = pd * 16 + addr;
      lampBitIndex[n++] = bit;
      allLampsMask |= (uint64_t)1 << bit;
    }
  }
}

const uint32_t DEMO_FLICKER_MS = 400;   // slow enough to watch a full fade
const uint32_t DEMO_BLINK_MS   = 500;
const uint32_t DEMO_CHASE_MS   = 250;
const uint8_t  DEMO_FLICKER_ON_PERCENT = 20;   // average share of lamps lit

uint32_t demoLastChange = 0;
uint8_t  demoChaseIdx   = 0;
bool     demoBlinkOn    = false;

void serviceDemo(uint32_t now) {
  switch (lampSource) {
    case LampSource::RandomFlicker:
      if (now - demoLastChange >= DEMO_FLICKER_MS) {
        demoLastChange = now;
        uint64_t bits = 0;
        for (uint8_t i = 0; i < LAMP_COUNT; i++) {
          if (random(100) < DEMO_FLICKER_ON_PERCENT) {
            bits |= (uint64_t)1 << lampBitIndex[i];
          }
        }
        publishFrame(bits);
      }
      break;

    case LampSource::Blink:
      if (now - demoLastChange >= DEMO_BLINK_MS) {
        demoLastChange = now;
        demoBlinkOn = !demoBlinkOn;
        publishFrame(demoBlinkOn ? allLampsMask : 0);
      }
      break;

    case LampSource::Chase:
      if (now - demoLastChange >= DEMO_CHASE_MS) {
        demoLastChange = now;
        publishFrame((uint64_t)1 << lampBitIndex[demoChaseIdx]);
        demoChaseIdx = (demoChaseIdx + 1) % LAMP_COUNT;
      }
      break;

    case LampSource::Live:
      break;
  }
}

// Cycle to the next source, and publish an empty frame so the outgoing mode's pattern fades away instead of being stranded on the lamps.
void nextLampSource() {
  switch (lampSource) {
    case LampSource::Live:          lampSource = LampSource::RandomFlicker; break;
    case LampSource::RandomFlicker: lampSource = LampSource::Blink;         break;
    case LampSource::Blink:         lampSource = LampSource::Chase;         break;
    case LampSource::Chase:         lampSource = LampSource::Live;          break;
  }

  demoLastChange = 0;
  demoChaseIdx   = 0;
  demoBlinkOn    = false;
  publishFrame(0);
}

void serviceModeSwitch(uint32_t now) {
  static bool     lastState  = HIGH;
  static uint32_t lastChange = 0;

  const bool sw = digitalRead(PIN_DEMO_SWITCH);
  if (sw != lastState && (now - lastChange) > DEBOUNCE_MS) {
    lastChange = now;
    lastState  = sw;
    if (sw == LOW) nextLampSource();   // active low
  }
}

#endif  // ENABLE_DEMO_MODES

// ==================================================================
// Controls
// ==================================================================

void servicePot(uint32_t now) {
  static uint32_t lastPoll = 0;
  static int16_t  lastRaw  = -1;

  if (now - lastPoll < POT_POLL_MS) return;
  lastPoll = now;

  const int16_t raw = analogRead(PIN_POT_FADE);
  if (lastRaw >= 0) {
    const int16_t moved = raw > lastRaw ? raw - lastRaw : lastRaw - raw;
    if (moved < POT_DEADBAND) return;
  }
  lastRaw = raw;

  const uint16_t riseMs = map(raw, 0, POT_MAX, FADE_IN_MIN_MS, FADE_IN_MAX_MS);
  fade.setTimes(riseMs, (uint16_t)(riseMs * FADE_OUT_RATIO));
}

// ==================================================================
// Load meter  (bench only - see ENABLE_LOAD_METER)
// ==================================================================
// Answers "how hard is the Teensy actually working, and what is the worst-case delay a fade tick can suffer?" - 
// the second being the number that matters, since loop()-driven fades are only smooth if no single pass runs long.
//
// Built on ARM_DWT_CYCCNT, the Cortex-M7's free-running cycle counter. It ticks at F_CPU_ACTUAL (600MHz here) and wraps every ~7.2 seconds, 
// which is harmless: every measurement subtracts two reads taken microseconds apart, and unsigned subtraction wraps correctly. 
// The counter is already enabled and proven - the TLC5947 driver's pulseGuard() leans on it via delayNanoseconds().
//
// WHAT "LOAD" MEANS HERE. loop() never sleeps; it spins. So the CPU is always executing something, and measuring "time inside loop()" 
// would report ~100% and tell you nothing. Instead the meter times only the blocks that do real work and divides by wall-clock cycles. 
// Idle passes cost nothing to measure because they aren't measured at all.
// - load — share of wall-clock cycles spent doing real work. My prediction is ~3-5%; if it reads wildly higher, 
//   suspect the meter before the firmware.
// - pass peak — the longest single fade-tick block in the last second. 
//   This is the one that matters. It's the worst-case delay a tick can suffer, and it's the direct test of the "jitter well under 
//   a millisecond against a 5 ms tick" claim. If it ever approaches 5000 µs, the loop-driven fade design is in trouble and the 
//   IntervalTimer fallback earns its keep.
// - tick and write — last/peak µs for the curve math and the bit-banged shift. 
//   write is the one to watch: ~150 µs is my estimate, never measured, and it's the number my whole architecture argument rests on.
// - frames — frames applied per second. ~120 live (AC zero-cross); in a demo mode it'll be much lower, 
//   since demos only publish on pattern changes.
//
// TWO CAVEATS, both small:
//   - An ISR that preempts a measured block has its cycles charged to that block. 
//     The five pin ISRs run ~9k/sec at ~100 cycles each (well under 1%), so this doesn't move the number. 
//     Note they only fire on live MPU traffic - on the bench, in a demo mode, ISR cost reads as zero because it is zero.
//   - The pot poll and demo pattern generation aren't instrumented: a few microseconds per second between them, 
//     far below the noise floor. Load is therefore a hair under-reported.

#if ENABLE_LOAD_METER

const uint32_t LOAD_REPORT_MS = 5000;

// One instrumented block's stats for the current reporting window.
//
// add() and reset() are members rather than free functions on purpose: the Arduino IDE auto-generates prototypes for 
// free functions and injects them at the top of the .ino, above this struct - so a free meterAccumulate(MeterStat&)
// would be prototyped before MeterStat exists and fail to compile. Members are never auto-prototyped, which sidesteps 
// it entirely. Don't "simplify" these back into free functions.
struct MeterStat {
  uint32_t total;   // cycles accumulated
  uint32_t last;    // most recent sample
  uint32_t peak;    // largest single sample
  uint32_t count;   // samples taken

  void add(uint32_t cycles) {
    total += cycles;
    last   = cycles;
    count++;
    if (cycles > peak) peak = cycles;
  }

  void reset() { total = 0; peak = 0; count = 0; }
};
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
void loop() {
  static uint32_t lastFadeMs = 0;
  const uint32_t now = millis();

#if ENABLE_DEMO_MODES
  serviceDemo(now);
  serviceModeSwitch(now);
#endif

  // A frame from whichever source is live becomes the fade engine's targets.
  uint64_t lampBits;
  if (takeFrame(lampBits)) {
    METER_BEGIN(frame);
    for (uint16_t ch = 0; ch < NUM_CHANNELS; ch++) {
      const uint8_t bit = channelToLampBit[ch];
      if (bit == DED) continue;
      fade.setTarget(ch, ((lampBits >> bit) & 1ULL) != 0, now);
    }
    METER_END(frame, meterFrame);
  }

  // Advance the fades on a regular tick. loop() has nothing else to do and its slowest pass is tlc.write() at ~150us,
  // so the jitter against a 5ms tick is well under a millisecond - far below anything the eye resolves.
  // (ENABLE_LOAD_METER measures that claim rather than trusting it: "pass peak" is the worst-case delay a tick can suffer.)
  if (now - lastFadeMs >= FADE_TICK_MS) {
    METER_BEGIN(work);
    lastFadeMs = now;

    METER_BEGIN(tick);
    fade.tick(now);
    METER_END(tick, meterTick);

    if (fade.dirty()) {
      for (uint16_t ch = 0; ch < NUM_CHANNELS; ch++) tlc.setPWM(ch, fade.level(ch));
      METER_BEGIN(write);
      tlc.write();
      METER_END(write, meterWrite);
      fade.clearDirty();
    }
    METER_END(work, meterWork);
  }

  servicePot(now);

#if ENABLE_LOAD_METER
  reportLoad(now);
#endif
}

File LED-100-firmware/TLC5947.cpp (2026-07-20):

#include "TLC5947.h"

// The datasheet's minimum XLAT/BLANK high pulse (T_WH1) is 30ns, and its
// XLAT-rise-to-BLANK-fall setup (T_SU2) is another 30ns. Back-to-back
// digitalWrite() calls on a 600MHz Teensy 4 probably clear both on their own,
// but "probably" is doing a lot of work in that sentence and the margin is
// nil. 50ns costs us nothing at a 5ms write cadence, so buy the margin.
static inline void pulseGuard() {
#if defined(__IMXRT1062__)   // Teensy 4.x
  delayNanoseconds(50);
#else
  delayMicroseconds(1);
#endif
}

// Sets numChannels from numDrivers and allocates the zeroed PWM buffer.
// Both constructors need exactly this, so it lives here rather than being
// copy-pasted into each.
void TLC5947::allocPwmBuffer() {
  numChannels = 24 * numDrivers;
  pwmBuffer = new uint16_t[numChannels]();   // () value-inits every channel to 0
}

TLC5947::TLC5947(uint16_t n, uint8_t clk, uint8_t data, uint8_t latch, int8_t blank)
  : numDrivers(n), useHardwareSPI(false), clockPin(clk), dataPin(data),
    latchPin(latch), blankPin(blank), spiBuf(nullptr), spiBufLen(0) {
  allocPwmBuffer();
}

TLC5947::TLC5947(uint16_t n, uint8_t latch, int8_t blank)
  : numDrivers(n), useHardwareSPI(true), clockPin(255), dataPin(255),
    latchPin(latch), blankPin(blank) {
  allocPwmBuffer();

  spiBufLen = (numChannels / 2) * 3;   // 2 channels (24 bits) pack into 3 bytes
  spiBuf = new uint8_t[spiBufLen];
}

TLC5947::~TLC5947() {
  delete[] pwmBuffer;
  delete[] spiBuf;   // delete[] on nullptr (software-SPI case) is a no-op
}

void TLC5947::begin() {
  pinMode(latchPin, OUTPUT);
  digitalWrite(latchPin, LOW);

  if (blankPin >= 0) {
    // Order matters. pinMode(OUTPUT) starts driving the pin at whatever the
    // output register already holds, which is LOW - so setting the level
    // first is what stops BLANK from dipping low on the way up. The datasheet
    // is emphatic here: the grayscale latch powers up holding garbage, and
    // BLANK must be high at power-on or the outputs will briefly show it.
    //
    // This only covers the window from begin() onward. Between the LEDs
    // getting power and begin() running, BLANK is still an undriven input;
    // only a pullup resistor on the board can hold it high across that gap.
    digitalWrite(blankPin, HIGH);
    pinMode(blankPin, OUTPUT);
  }

  if (useHardwareSPI) {
    SPI.begin();
  } else {
    pinMode(clockPin, OUTPUT);
    pinMode(dataPin, OUTPUT);
    digitalWrite(clockPin, LOW);
  }

  // Give the grayscale latch a defined value (all channels off) as early as
  // we can, so it isn't showing its power-on garbage. The constructor already
  // zeroed pwmBuffer, so this just shifts it out and latches.
  //
  // A bare latch pulse, deliberately NOT the BLANK-bracketed write(): there is
  // no live picture to protect from a mid-PWM glitch, and write()'s trailing
  // outputsOn() would drive BLANK low - which would defeat the whole point in
  // the with-BLANK case by un-holding the outputs. Leaving BLANK as it stands
  // (high where we have the pin, so still hard-off; hardware-tied otherwise)
  // is what keeps this safe in every wiring.
  if (useHardwareSPI) shiftOutHardware();
  else shiftOutSoft();
  digitalWrite(latchPin, HIGH);
  pulseGuard();
  digitalWrite(latchPin, LOW);
}

void TLC5947::setPWM(uint16_t chan, uint16_t pwm) {
  if (chan >= numChannels) return;
  if (pwm > 4095) pwm = 4095;
  pwmBuffer[chan] = pwm;
}

uint16_t TLC5947::getPWM(uint16_t chan) const {
  if (chan >= numChannels) return 0;
  return pwmBuffer[chan];
}

void TLC5947::shiftOutSoft() {
  for (int32_t c = (int32_t)numChannels - 1; c >= 0; c--) {
    for (int8_t b = 11; b >= 0; b--) {
      digitalWrite(clockPin, LOW);
      digitalWrite(dataPin, (pwmBuffer[c] & (1 << b)) ? HIGH : LOW);
      digitalWrite(clockPin, HIGH);
    }
  }
  digitalWrite(clockPin, LOW);
}

void TLC5947::shiftOutHardware() {
  // Pack pairs of 12-bit channels into 3 bytes (24 bits), MSB first, highest
  // channel index first. That matches both the bit-banged path above and the
  // chip's own layout: the 288-bit register runs from OUT0's LSB at bit 0 up
  // to OUT23's MSB at bit 287, and data shifts toward the MSB end - so the
  // first bit clocked in has to be the highest channel's MSB.
  //
  // Note SPI.transfer(buf, len) is full-duplex and writes the received bytes
  // back over spiBuf. Harmless, since we repopulate it from scratch every
  // call, but don't expect its contents to survive.
  uint16_t bi = 0;
  for (int32_t c = (int32_t)numChannels - 1; c >= 1; c -= 2) {
    uint16_t hi = pwmBuffer[c];
    uint16_t lo = pwmBuffer[c - 1];
    spiBuf[bi++] = hi >> 4;
    spiBuf[bi++] = ((hi & 0xF) << 4) | (lo >> 8);
    spiBuf[bi++] = lo & 0xFF;
  }
  SPI.beginTransaction(SPISettings(spiClockHz, MSBFIRST, SPI_MODE0));
  SPI.transfer(spiBuf, spiBufLen);
  SPI.endTransaction();
}

void TLC5947::write() {
  if (useHardwareSPI) shiftOutHardware();
  else shiftOutSoft();

  // Blank across the latch pulse, and only the latch pulse.
  //
  // An XLAT rising edge on its own forces every output off until the next
  // grayscale display period begins, and it does NOT reset the grayscale
  // counter. So a bare latch would leave the LEDs dark for whatever remains
  // of the period in flight - averaging half of one, and a period is 4096
  // steps of a 4MHz internal oscillator, so ~0.5ms. At our write rate that
  // is a real, and worse, a fade-only dimming.
  //
  // Pulsing BLANK sidesteps that: BLANK high resets the grayscale counter to
  // zero, so dropping it low again starts a fresh display period immediately
  // rather than waiting out the old one. Hence blank, latch, unblank.
  //
  // Blanking across the whole shift-out instead would be far worse - that's
  // hundreds of microseconds dark rather than hundreds of nanoseconds.
  outputsOff();
  digitalWrite(latchPin, HIGH);
  pulseGuard();                    // XLAT high >= 30ns (T_WH1)
  digitalWrite(latchPin, LOW);
  pulseGuard();                    // XLAT high -> BLANK low >= 30ns (T_SU2)
  outputsOn();
}

void TLC5947::outputsOn() {
  if (blankPin >= 0) digitalWrite(blankPin, LOW);
}

void TLC5947::outputsOff() {
  if (blankPin >= 0) digitalWrite(blankPin, HIGH);
}

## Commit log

2025-03-06 pcb tweaks
    [LED-100-B_Cu.gbr, LED-100-B_Mask.gbr, LED-100-B_Silkscreen.gbr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]
2025-03-19 use SPI instead of I2C
    [LED-100.kicad_pcb, LED-100.kicad_sch]
2025-03-19 tweaks & cleanup
    [LED-100.kicad_pcb, LED-100.kicad_sch]
2025-03-27 rev3 first draft
    [LED-100.kicad_pcb, LED-100.kicad_sch]
2025-04-04 Angled teensy + updates (#1)
    * diagonal teensy, pin reassignments, tweaks
    * added a switch, updated to kicad 9
    * rev3
    [LED-100-B_Cu.gbr, LED-100-B_Mask.gbr, LED-100-B_Silkscreen.gbr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]
2025-04-29 new teensyduino code
2026-07-20 Rev 5
    [LED-100-B_Cu.gbr, LED-100-B_Mask.gbr, LED-100-B_Silkscreen.gbr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]
2026-07-22 project reorg
    [LED-100-B_Cu.gbr, LED-100-B_Mask.gbr, LED-100-B_Silkscreen.gbr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]
2026-07-23 lil tweaks
    [LED-100.kicad_sch]
